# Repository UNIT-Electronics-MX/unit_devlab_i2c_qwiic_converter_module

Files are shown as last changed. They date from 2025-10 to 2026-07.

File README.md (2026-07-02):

# DevLab: I2C Qwiic Converter Module

A bidirectional I2C level shifter module for seamless 3.3V↔5V communication. Features integrated voltage regulators and Qwiic/STEMMA QT connectors for easy sensor integration.

## Key Features

- **Bidirectional Level Shifting:** DIP switch selectable for buck (5V→3.3V) or boost (3.3V→5V)
- **Qwiic/STEMMA QT Compatible:** Daisy-chain multiple sensors effortlessly
- **Compact Design:** Breadboard-friendly with minimal footprint
- **No Additional Wiring:** Integrated power conversion for mixed-voltage systems

<div align="center">
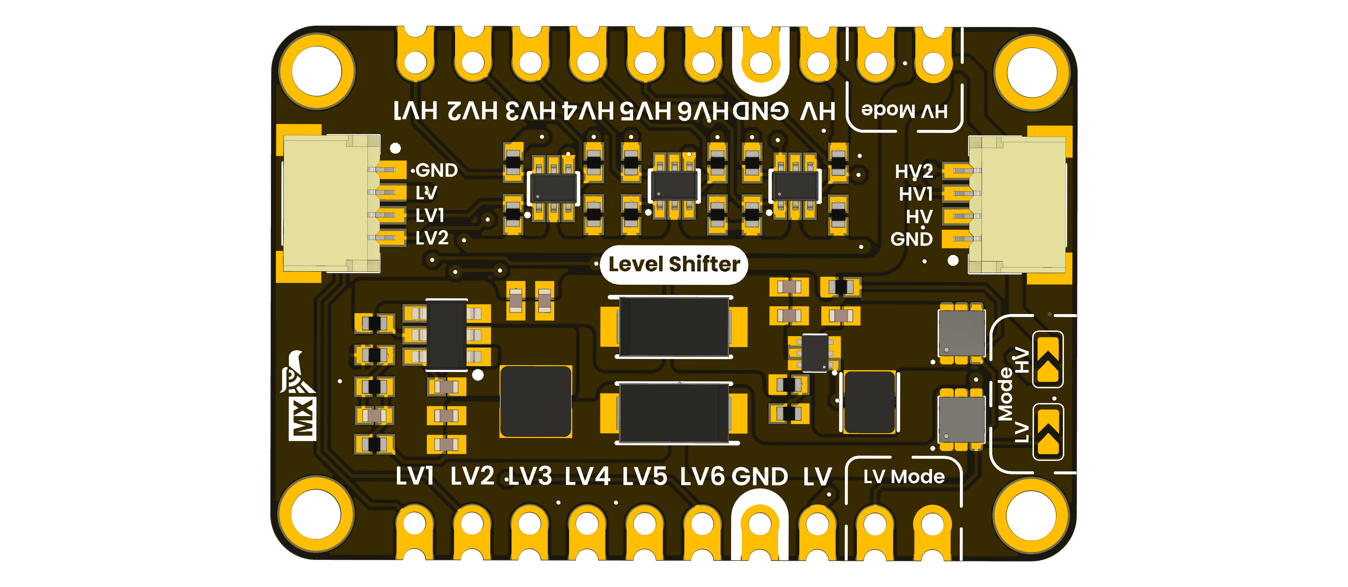
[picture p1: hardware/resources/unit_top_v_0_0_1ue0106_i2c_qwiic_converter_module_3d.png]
  
  <p><em>Development Board</em></p>
</div>

## Quick Start

<div align="center">

[](#)
[](./hardware/unit_datasheet_v_1_0_0_devlab_i2c_Qwiic_converter_module.pdf)
[](#)
[](./software/examples/)

</div >

## Specifications

<div align="center">

| Specification | Value |
|---|---|
| Input Voltage (High) | 5V ± 0.3V |
| Input Voltage (Low) | 3.3V ± 0.1V |
| I2C Speed | 100 kHz - 400 kHz |
| Connector | Qwiic/STEMMA QT |
| Operating Temp | 0°C to 50°C |

</div>

## Use Cases

- Mixed-voltage IoT projects
- Multi-sensor prototyping
- I2C device bridging

## 📝 License

Licensed under the **MIT License**. See [`LICENSE.md`](LICENSE.md).

<div align="center">
  <sub>Created by UNIT Electronics</sub>
</div>

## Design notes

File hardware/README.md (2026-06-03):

# Hardware

<div align="center">
<a href="https://github.com/UNIT-Electronics-MX/unit_devlab_i2c_qwiic_converter_module/blob/main/hardware/unit_sch_v_1_0_0_ue0106_i2c_qwiic_converter_module.pdf">
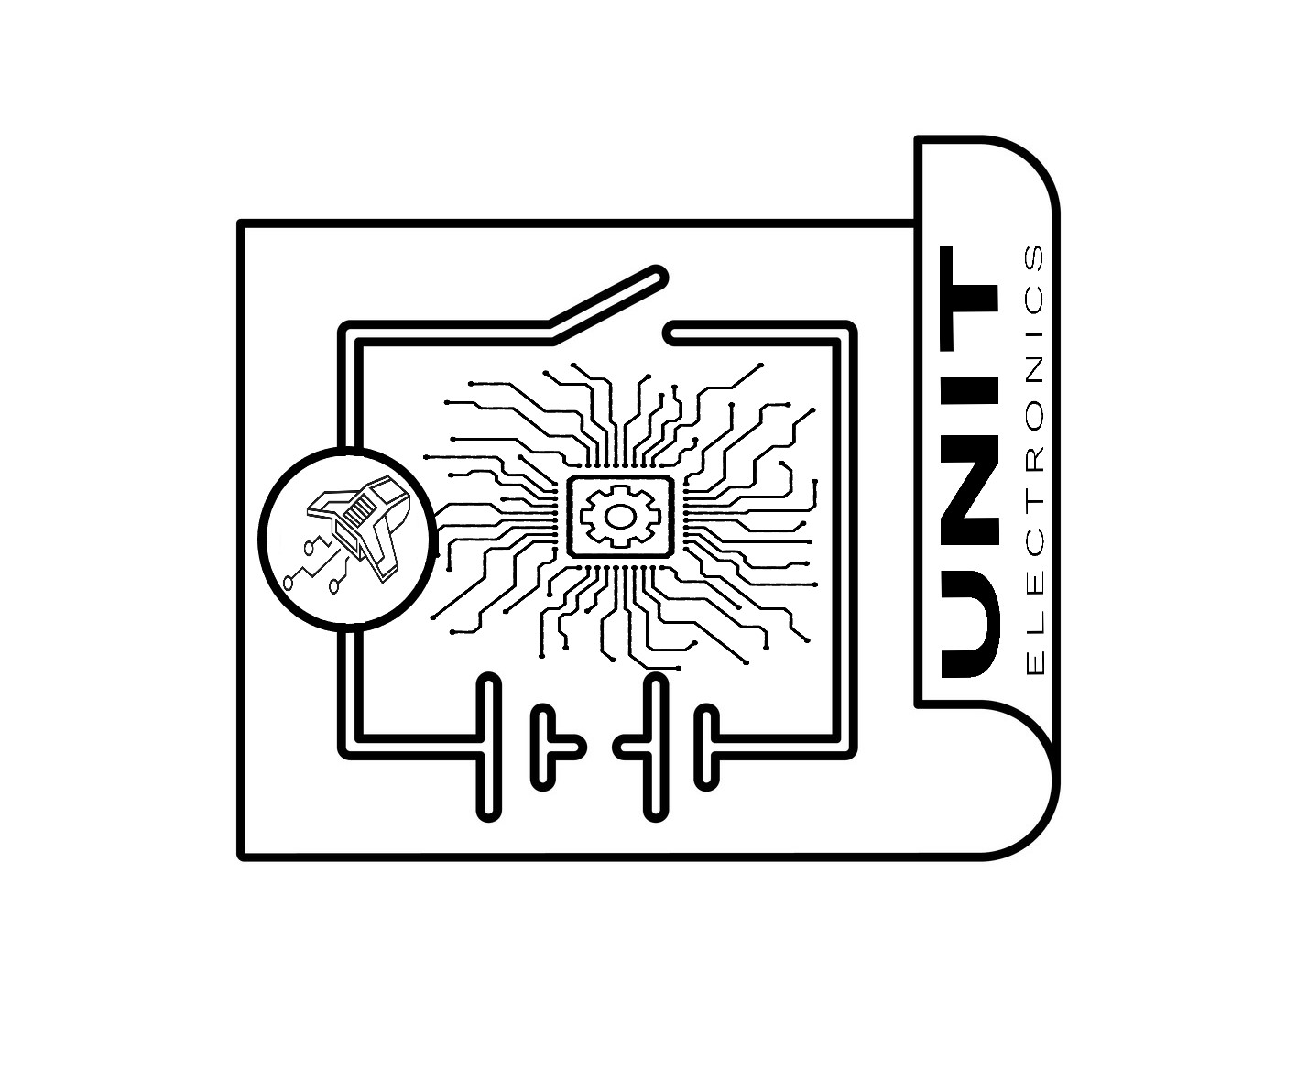
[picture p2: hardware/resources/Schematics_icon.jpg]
<br/>
Schematic
</a>
</div>

---

## Electrical Characteristics

| Parameter | Description | Min | Typ | Max | Unit |
|---|---|---|---|---|---|
| VIN | Input supply voltage for module operation | 2.5 | 3.3 / 5.0 | 5.5 | V |
| VLV | Low-voltage rail operating range | 1.8 | 3.3 | 5.0 | V |
| VHV | High-voltage rail operating range | 3.3 | 5.0 | V |
| IOUT-LV | Maximum output current for LV rail | - | - | 1 | A |
| IOUT-HV | Maximum output current for HV rail | - | - | 1 | A |
| VIH | Input high-level voltage for I²C logic | 0.7 × VCC | - | - | V |
| VIL | Input low-level voltage for I²C logic | - | - | 0.3 × VCC | V |
| VOH | Output high-level voltage for I²C logic | 0.8 × VCC | - | - | V |
| VOL | Output low-level voltage for I²C logic | - | - | 0.2 × VCC | V |
| fI2C | Supported I²C bus frequency | 0 | 100 | 400 | kHz |
| TAMB | Recommended operating ambient temperature | -20 | 25 | 85 | °C |
| RPULLUP | Integrated pull-up resistor value | - | 10 | - | kΩ |
| ESD | ESD protection level (HBM typical) | - | ±2 | - | kV |

> **Note 1:** Maximum output current depends on thermal dissipation, PCB layout, and input voltage conditions.

> **Note 2:** The module integrates bidirectional MOSFET-based level shifters optimized for open-drain I²C communication.

> **Note 3:** Qwiic/STEMMA QT connectors share the same I²C bus signals (VCC, GND, SDA, SCL) for daisy-chain operation.

> **Note 4:** Operating voltage ranges may vary depending on external power configuration and selected LV/HV mode.

## Pinout

<div align="center">
<a href="unit_pinout_v_1_0_0_ue0106_convertidor_qwiic_en.pdf">
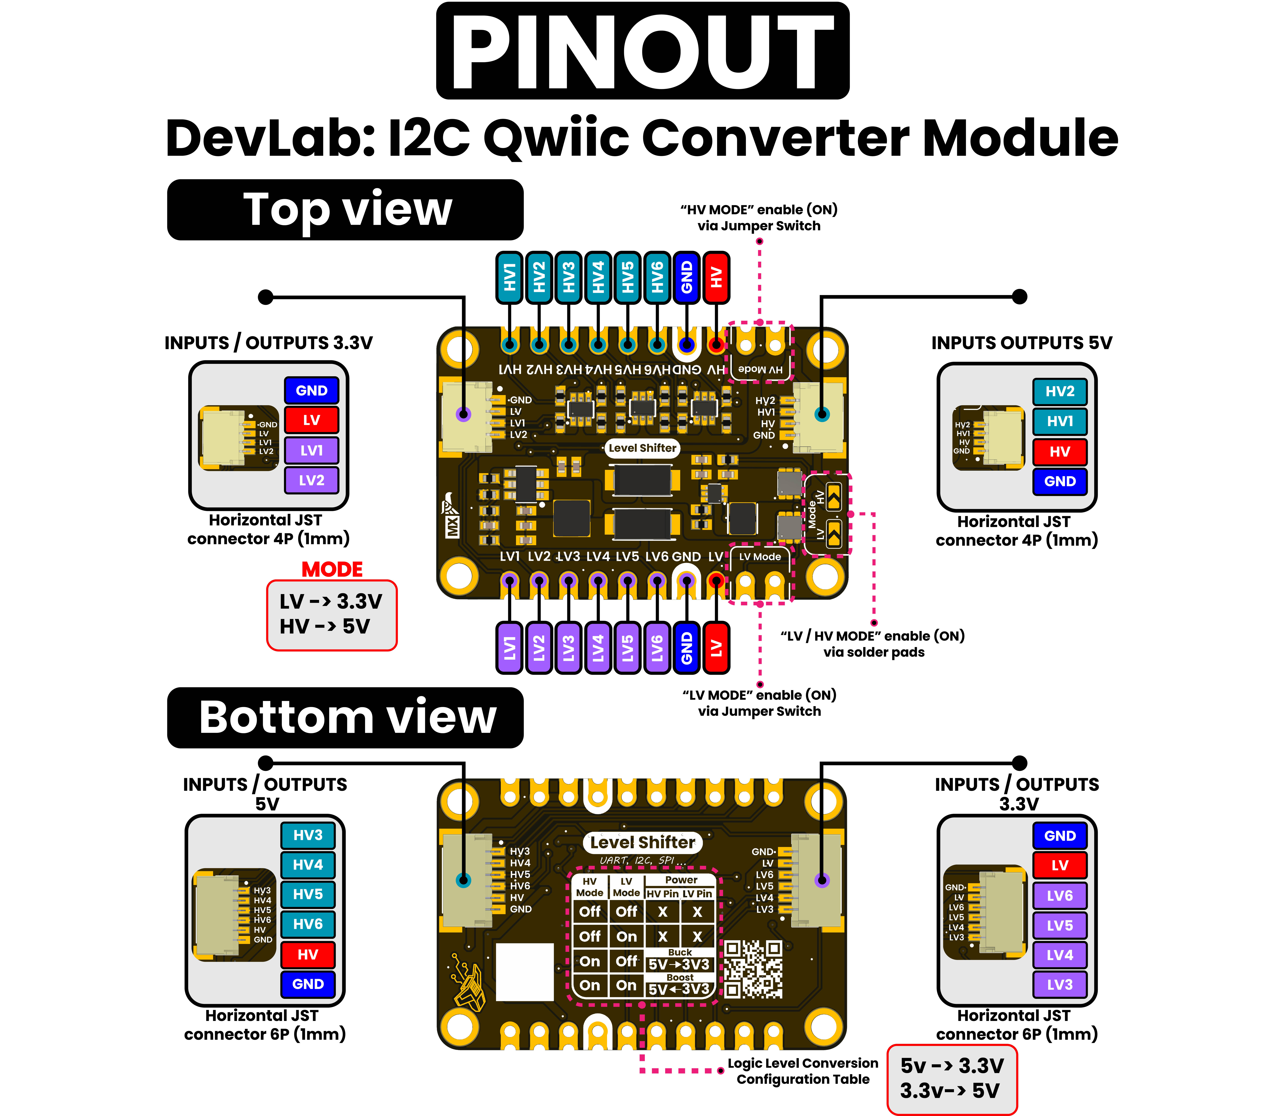
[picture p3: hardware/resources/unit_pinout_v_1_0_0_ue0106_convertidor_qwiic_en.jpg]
<br/>
Pinout
</a>
</div>

### Pin & Connector Layout

| Pin Label | Function | Notes |
|---|---|---|
| VCC | Power Supply | 3.3V or 5V |
| GND | Ground | Common ground for all components |

---

## Dimensions

<div align="center">
<a href="./resources/unit_dimensions_v_1_0_0_ue0106_i2c_qwiic_converter_module.png">
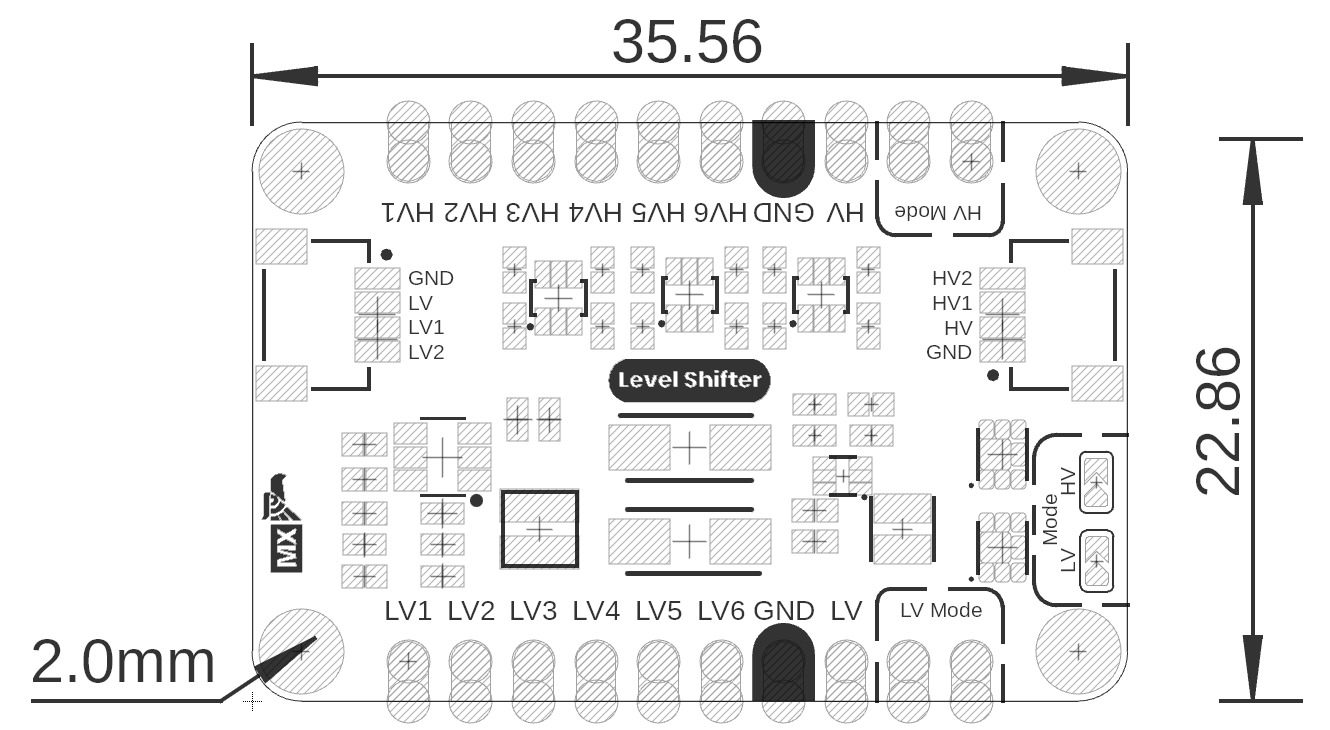
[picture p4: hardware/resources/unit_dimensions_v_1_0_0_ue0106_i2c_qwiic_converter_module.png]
<br/>
Dimensions
</a>
</div>

---

## Topology

<div align="center">
<a href="./resources/unit_topology_v_1_0_0_ue0106_i2c_qwiic_converter_module.png">
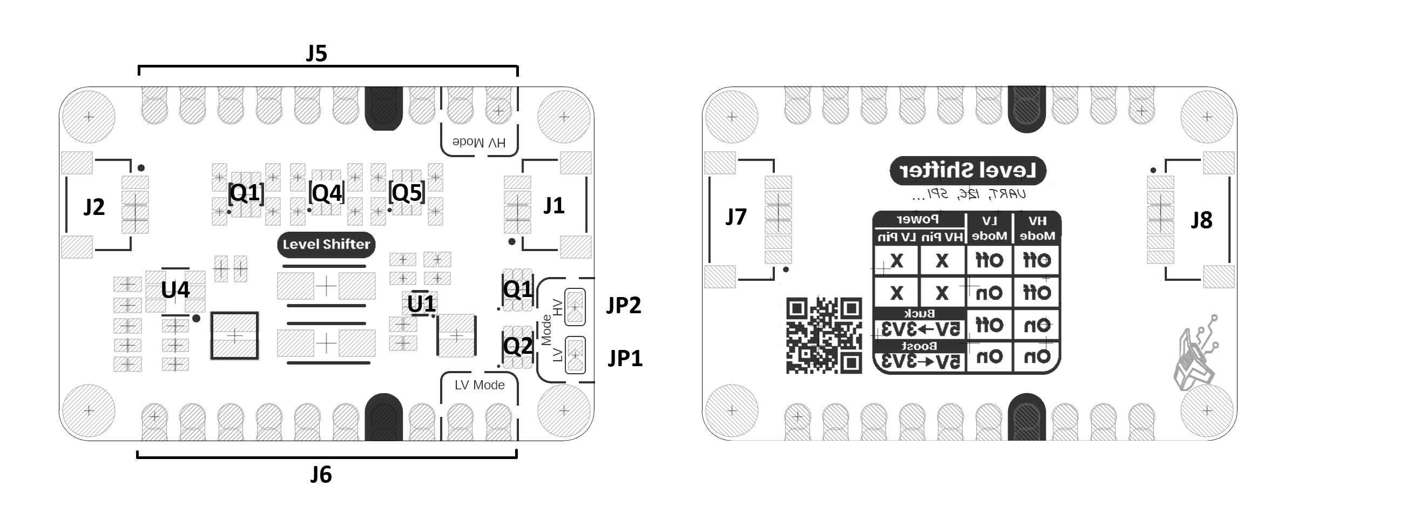
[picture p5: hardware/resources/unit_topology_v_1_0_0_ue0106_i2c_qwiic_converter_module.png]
<br/>
Topology
</a>
</div>

### Topology Description

| Ref. | Description |
|---|---|
| U1 | Boost converter circuit based on TPS61023 for LV power rail generation |
| U4 | Buck converter circuit based on TPS54302DDCT for HV power rail generation |
| Q1, Q4, Q5 | Bidirectional I²C level shifter circuits based on 2N7002KDW MOSFETs |
| Q2, Q3 | Power switching MOSFET stage for voltage rail selection/control |
| J1, J2 | Qwiic/STEMMA QT connectors (JST 1.0 mm pitch) for I²C interface |
| J5, J6 | Castellated 1x10 pin headers (2.54 mm pitch) for external module integration |
| J7, J8 | 1x6 pin headers/connectors for HV/LV mode configuration and external interfacing |
| JP1 | LV Mode solder jumper selector |
| JP2 | HV Mode solder jumper selector |

> **Note:** The module also includes a Qwiic/STEMMA QT connector carrying the same four signals (VCC, GND, SDA, SCL) for effortless daisy-chaining.

---

## Functional Description

The **DevLab Qwiic I²C Converter Module** is a bidirectional voltage level shifter designed for seamless communication between low-voltage and high-voltage I²C devices. The module enables safe interfacing between 3.3V and 5V systems using MOSFET-based bidirectional level translation.

The design integrates dedicated boost and buck power conversion stages to generate and regulate the required voltage rails for both LV and HV domains. Multiple Qwiic/STEMMA QT connectors and castellated interfaces simplify integration with embedded systems, development boards, sensors, and expansion modules.

### Features

- Bidirectional I²C level shifting
- Qwiic/STEMMA QT compatibility
- Castellated edge connections for embedded integration
- Configurable LV/HV operating modes
- 3.3V and 5V logic interoperability
- Daisy-chain I²C connectivity

### Typical Applications

- Sensor interfacing
- Mixed-voltage embedded systems
- Rapid prototyping
- Development board expansion
- Qwiic/STEMMA QT ecosystem integration

# References

- [TPS61023 Datasheet](https://www.ti.com/lit/ds/symlink/tps61023.pdf)
- [TPS54302 Datasheet](https://www.ti.com/lit/ds/symlink/tps54302.pdf)
- [2N7002KDW Datasheet](https://assets.nexperia.com/documents/data-sheet/2N7002KDW.pdf)

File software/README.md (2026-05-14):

## Buck Mode

### 5 V to 3.3 V Level Conversion

To enable **Buck Mode**, the module must be configured to convert a high-voltage signal into a lower-voltage signal. In this case, the input signal comes from a **5 V microcontroller**, and the module shifts it down to a **3.3 V logic level**.

There are two ways to enable this mode:

1. Place a jumper on the **HV Mode** pins.
2. Solder the exposed pads labeled **HV Mode** for a permanent configuration.

In **Buck Mode**, the input signal must be connected to one of the **HV channels**, from **HV1 to HV6**. The corresponding converted output signal will be available on the matching **LV channel**, from **LV1 to LV6**.

For example:

<div align="center">

| Input Signal | Converted Output |
|---|---|
| `HV1` | `LV1` |
| `HV2` | `LV2` |
| `HV3` | `LV3` |
| `HV4` | `LV4` |
| `HV5` | `LV5` |
| `HV6` | `LV6` |

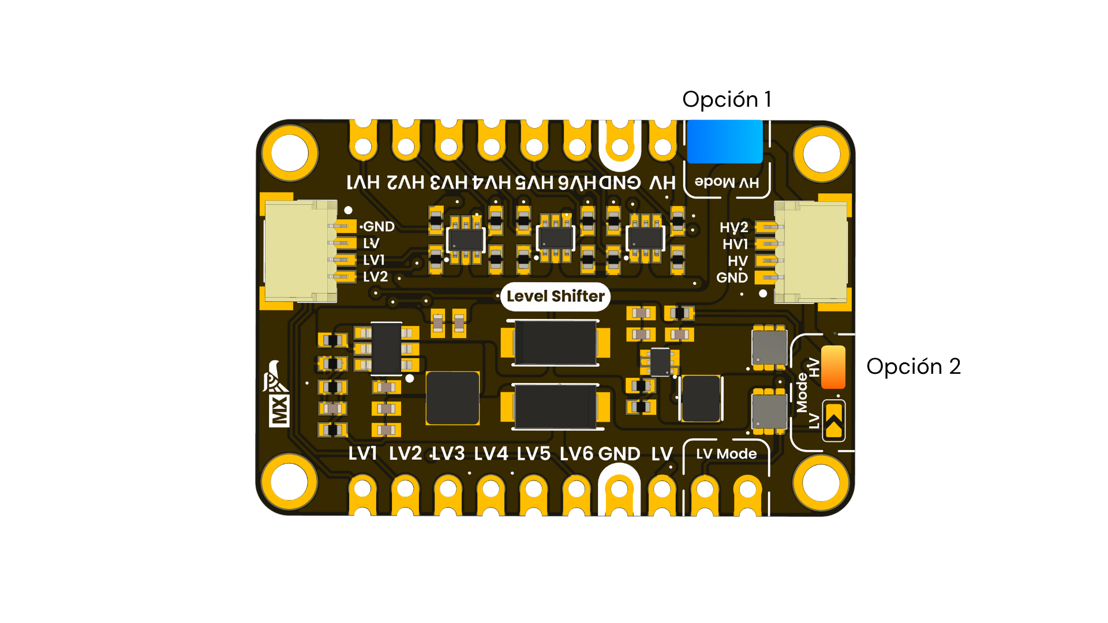
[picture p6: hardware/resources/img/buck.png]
Buck mode jumper configuration
  
  <p><em>Buck Mode jumper configuration</em></p>
</div>

---

## Example Circuit

The following image shows a basic test circuit using an **Arduino UNO** and the **I2C QWIIC Converter Module**.

In this setup, the Arduino UNO generates a square wave. Since the Arduino UNO operates with **5 V logic**, the generated signal enters the converter module through one of the **HV channels**. In this example, the signal is connected to **HV4**, which corresponds to **High Voltage Channel 1**.

The **5 V** supply from the Arduino is connected to the **HV** pin of the module, defining the high-voltage side as **5 V**. After placing the required jumper on the **HV Mode** pins, the module converts the square wave from **5 V** to **3.3 V**. The converted signal can then be measured or used from the corresponding low-voltage output, **LV4**.

To verify the conversion, an oscilloscope is used:

- **Oscilloscope Channel 1:** connected to **HV4**, where the original **5 V signal** from the microcontroller is observed.
- **Oscilloscope Channel 2:** connected to **LV4**, where the converted **3.3 V signal** is observed.

This test makes it possible to compare both signals and confirm that the module is correctly shifting the logic level from **5 V to 3.3 V**.

<div align="center">
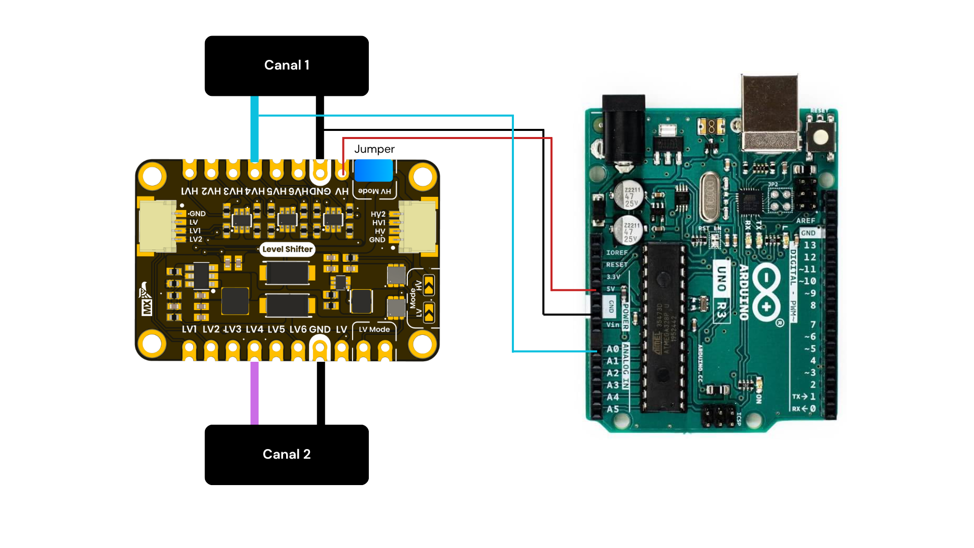
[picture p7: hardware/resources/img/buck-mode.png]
Buck mode test circuit
  
  <p><em>Buck Mode test circuit</em></p>
</div>

## Boost Mode

### 3.3 V to 5 V Level Conversion

To enable **Boost Mode**, the module must be configured to convert a low-voltage signal into a higher-voltage signal. In this case, the input signal comes from a **3.3 V microcontroller**, and the module shifts it to a **5 V logic level**.

There are two ways to enable this mode:

1. Place one jumper on the **HV Mode** pins and another jumper on the **LV Mode** pins.
2. Solder the exposed pads labeled **HV Mode** and **LV Mode** for a permanent configuration.

<div align="center">
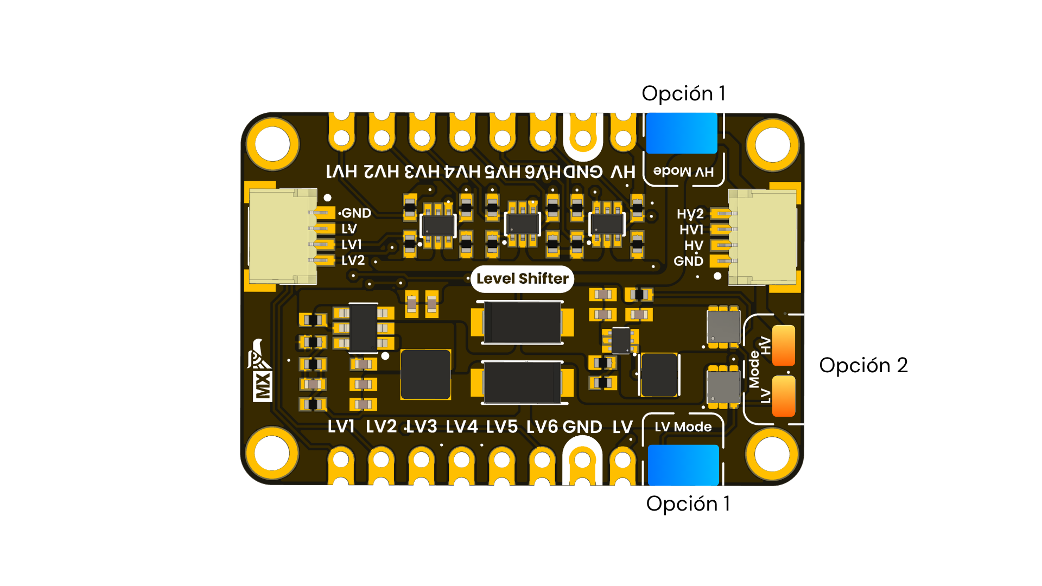
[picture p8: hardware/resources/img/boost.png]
Boost mode jumper configuration
  
  <p><em>Boost Mode jumper configuration</em></p>
</div>

---

## Example Circuit

The following image shows a basic test circuit using the **UNIT Pulsar C6** development board and the **I2C QWIIC Converter Module**.

In this setup, a **JST QWIIC cable** is connected from the development board to the level converter module. The square wave generated by the microcontroller on **GPIO6** is connected to **LV1**, which corresponds to **Low Voltage Channel 1**. The microcontroller supply voltage is also connected to the **LV** pin, defining the low-voltage side as **3.3 V**.

After placing the required jumpers on the **HV Mode** and **LV Mode** terminals, the module converts the square wave from **3.3 V** to **5 V**. This allows the signal generated by the microcontroller to be used with circuits or devices that require **5 V logic levels**.

To verify the conversion, an oscilloscope is used:

- **Oscilloscope Channel 1:** connected to **HV1**, where the converted **5 V signal** is observed.
- **Oscilloscope Channel 2:** connected to **LV1**, where the original **3.3 V signal** from the microcontroller is observed.

This test makes it possible to compare both signals and confirm that the module is correctly shifting the logic level from **3.3 V to 5 V**.

<div align="center">
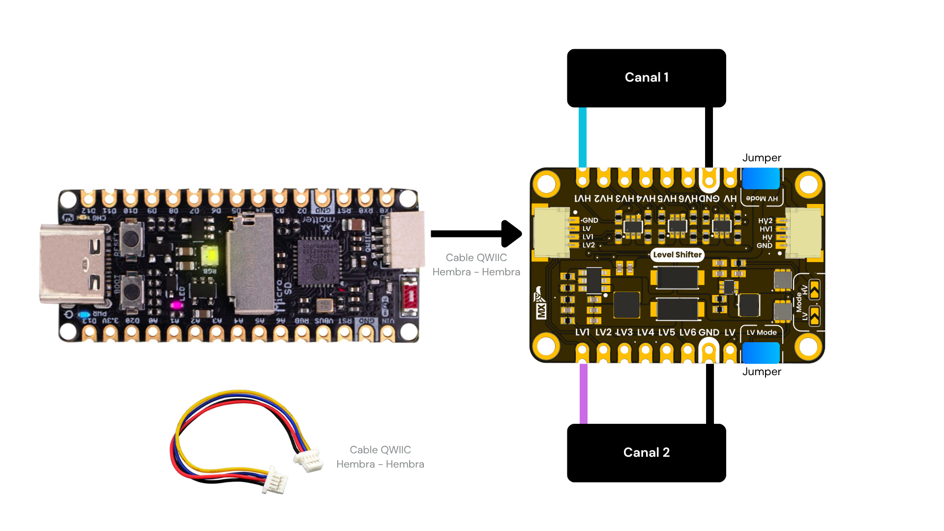
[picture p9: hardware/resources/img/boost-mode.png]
Boost mode test circuit
  
  <p><em>Boost Mode test circuit</em></p>
</div>

---

## Oscilloscope Verification

The oscilloscope capture shows the behavior of the signal before and after passing through the level converter module.

In this test, the original square wave is generated by the **UNIT Pulsar C6** microcontroller at **3.3 V logic level** and is applied to the low-voltage side of the module. After the signal passes through the converter in **Boost Mode**, the output signal is shifted to approximately **5 V logic level**.

The two oscilloscope channels allow both signals to be compared at the same time:

- **Channel 1:** original signal on the **LV side**, approximately **3.3 V**.
- **Channel 2:** converted signal on the **HV side**, approximately **5 V**.

Both waveforms keep the same timing behavior, including the pulse width, period, and duty cycle. The main difference between them is the voltage amplitude. This confirms that the module is correctly converting the logic level from **3.3 V to 5 V** without modifying the shape of the digital signal.

<div align="center">
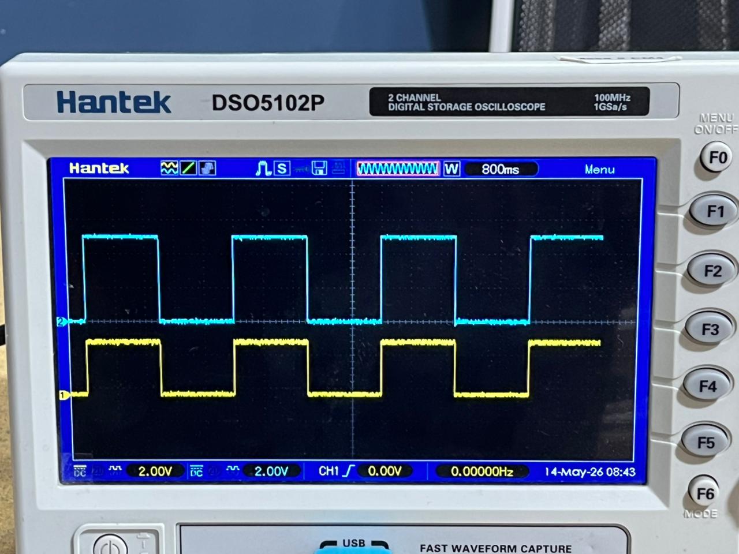
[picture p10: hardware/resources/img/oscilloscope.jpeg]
Boost mode oscilloscope verification
  
  <p><em>Boost Mode oscilloscope verification</em></p>
</div>

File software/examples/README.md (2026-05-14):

# Software Examples

In this example, the microcontroller generates a slow square wave on **GPIO6**. Since the microcontroller operates at **3.3 V logic**, the output signal is originally a **3.3 V digital pulse train**.

The signal is then connected to the **I2C QWIIC Converter Module**, which works as a logic level converter. In this configuration, the module converts the input signal from **3.3 V to 5 V**, allowing the square wave generated by the microcontroller to be observed or used as a **5 V logic signal** at the module output.

This test is useful to verify the module’s level-shifting behavior and to confirm that a low-voltage digital signal from a 3.3 V microcontroller can be safely adapted for circuits or devices that require 5 V logic levels.

---

## Arduino C++ Version

```cpp
const int pulsePin = 6;      // GPIO6
const int highTime = 2000;   // HIGH time: 2000 ms = 2 seconds
const int lowTime = 2000;    // LOW time: 2000 ms = 2 seconds

void setup() {
  pinMode(pulsePin, OUTPUT); // Configure GPIO6 as an output
}

void loop() {
  digitalWrite(pulsePin, HIGH); // Set GPIO6 HIGH
  delay(highTime);              // Wait 2 seconds

  digitalWrite(pulsePin, LOW);  // Set GPIO6 LOW
  delay(lowTime);               // Wait 2 seconds
}
```

---

## Arduino C++ Explanation

This program generates a slow digital pulse signal on **GPIO6**.

```cpp
const int pulsePin = 6;
```

This line defines the output pin. In this case, the pulse train will be generated on **GPIO6**.

```cpp
const int highTime = 2000;
const int lowTime = 2000;
```

These constants define how long the signal stays in each state. In Arduino, the `delay()` function uses milliseconds, so `2000 ms` is equal to `2 seconds`.

```cpp
pinMode(pulsePin, OUTPUT);
```

This line configures GPIO6 as a digital output pin.

```cpp
digitalWrite(pulsePin, HIGH);
```

This sets GPIO6 to a HIGH logic level. Depending on the board, this is usually **3.3 V** or **5 V**.

```cpp
delay(highTime);
```

This keeps the pin HIGH for 2 seconds.

```cpp
digitalWrite(pulsePin, LOW);
```

This sets GPIO6 to a LOW logic level, usually **0 V**.

```cpp
delay(lowTime);
```

This keeps the pin LOW for 2 seconds.

Since the code is inside `loop()`, the sequence repeats forever.

---

## MicroPython Version

```python
from machine import Pin
from time import sleep

pulse_pin = Pin(6, Pin.OUT)  # Configure GPIO6 as an output

high_time = 2  # HIGH time: 2 seconds
low_time = 2   # LOW time: 2 seconds

while True:
    pulse_pin.value(1)  # Set GPIO6 HIGH
    sleep(high_time)    # Wait 2 seconds

    pulse_pin.value(0)  # Set GPIO6 LOW
    sleep(low_time)     # Wait 2 seconds
```

---

## MicroPython Explanation

This MicroPython program performs the same task as the Arduino C++ version: it generates a slow pulse train on **GPIO6**.

```python
from machine import Pin
from time import sleep
```

The `Pin` class is used to configure and control GPIO pins. The `sleep()` function is used to pause the program for a specific number of seconds.

```python
pulse_pin = Pin(6, Pin.OUT)
```

This line configures **GPIO6** as a digital output.

```python
high_time = 2
low_time = 2
```

These variables define how long the signal stays HIGH and LOW. In MicroPython, `sleep()` uses seconds, so the value `2` means 2 seconds.

```python
while True:
```

This creates an infinite loop. The pulse train will continue running as long as the board is powered.

```python
pulse_pin.value(1)
```

This sets GPIO6 to a HIGH logic level.

```python
sleep(high_time)
```

This keeps the signal HIGH for 2 seconds.

```python
pulse_pin.value(0)
```

This sets GPIO6 to a LOW logic level.

```python
sleep(low_time)
```

This keeps the signal LOW for 2 seconds.

---

## Signal Behavior

Both programs generate the following signal:

```text
HIGH for 2 seconds
LOW for 2 seconds
HIGH for 2 seconds
LOW for 2 seconds
...
```

The total period of the signal is:

```text
Period = HIGH time + LOW time
Period = 2 s + 2 s
Period = 4 s
```

The frequency is:

```text
Frequency = 1 / Period
Frequency = 1 / 4 s
Frequency = 0.25 Hz
```

The duty cycle is:

```text
Duty Cycle = HIGH time / Period × 100
Duty Cycle = 2 s / 4 s × 100
Duty Cycle = 50%
```

---

## Summary

| Parameter | Value |
|---|---:|
| GPIO pin | GPIO6 |
| HIGH time | 2 seconds |
| LOW time | 2 seconds |
| Period | 4 seconds |
| Frequency | 0.25 Hz |
| Duty cycle | 50% |

The Arduino version uses `digitalWrite()` and `delay()`, while the MicroPython version uses `Pin.value()` and `sleep()`.

Both versions are useful for testing GPIO outputs, LEDs, logic level converters, oscilloscopes, or digital input circuits.

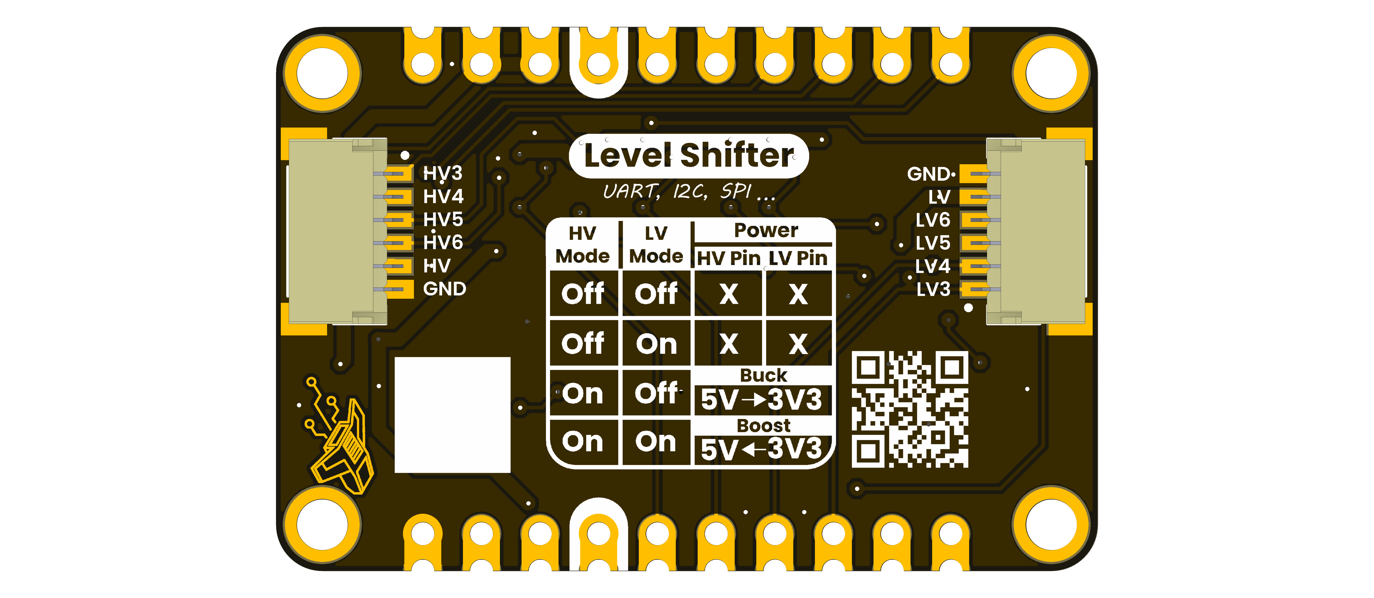
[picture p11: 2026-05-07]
docs/hardware/resources/unit_btm_v_0_0_1ue0106_i2c_qwiic_converter_module_3d.png

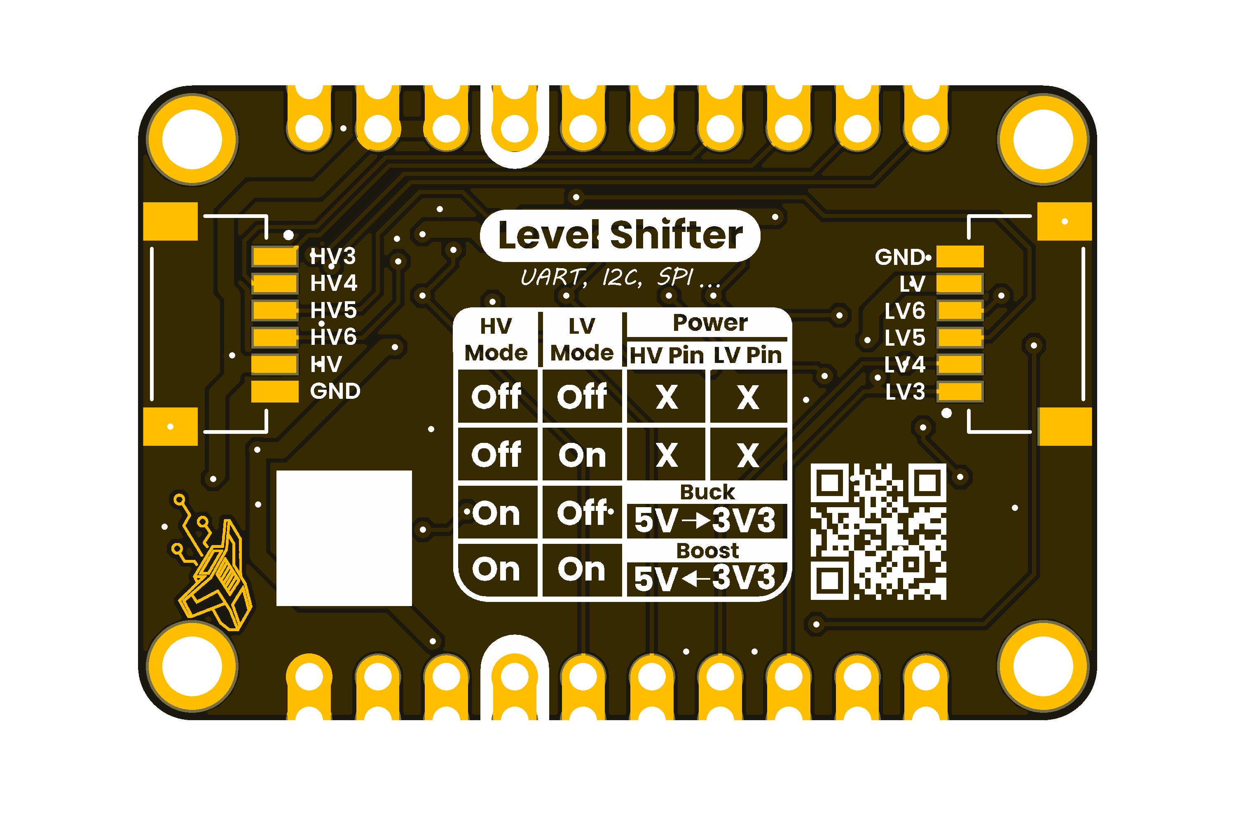
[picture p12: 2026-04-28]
docs/hardware/resources/v1/unit_btm_v_0_0_1_ue0116_i2c_qwiic_converter_module.jpg

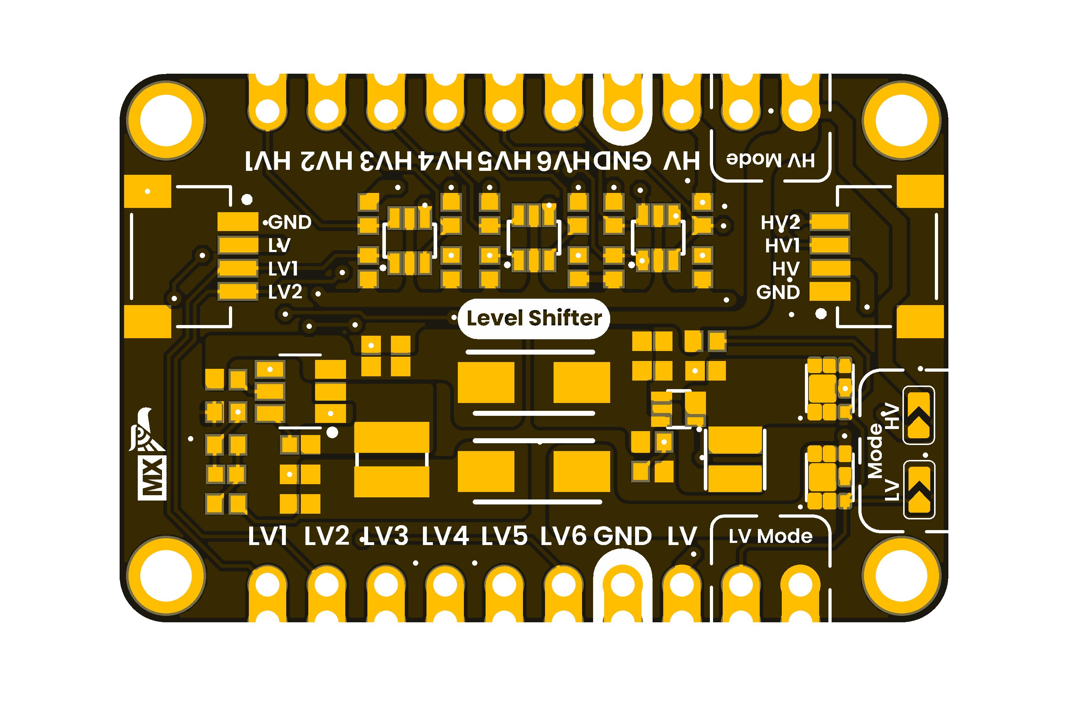
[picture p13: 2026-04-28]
docs/hardware/resources/v1/unit_top_v_0_0_1_ue0116_i2c_qwiic_converter_module.jpg

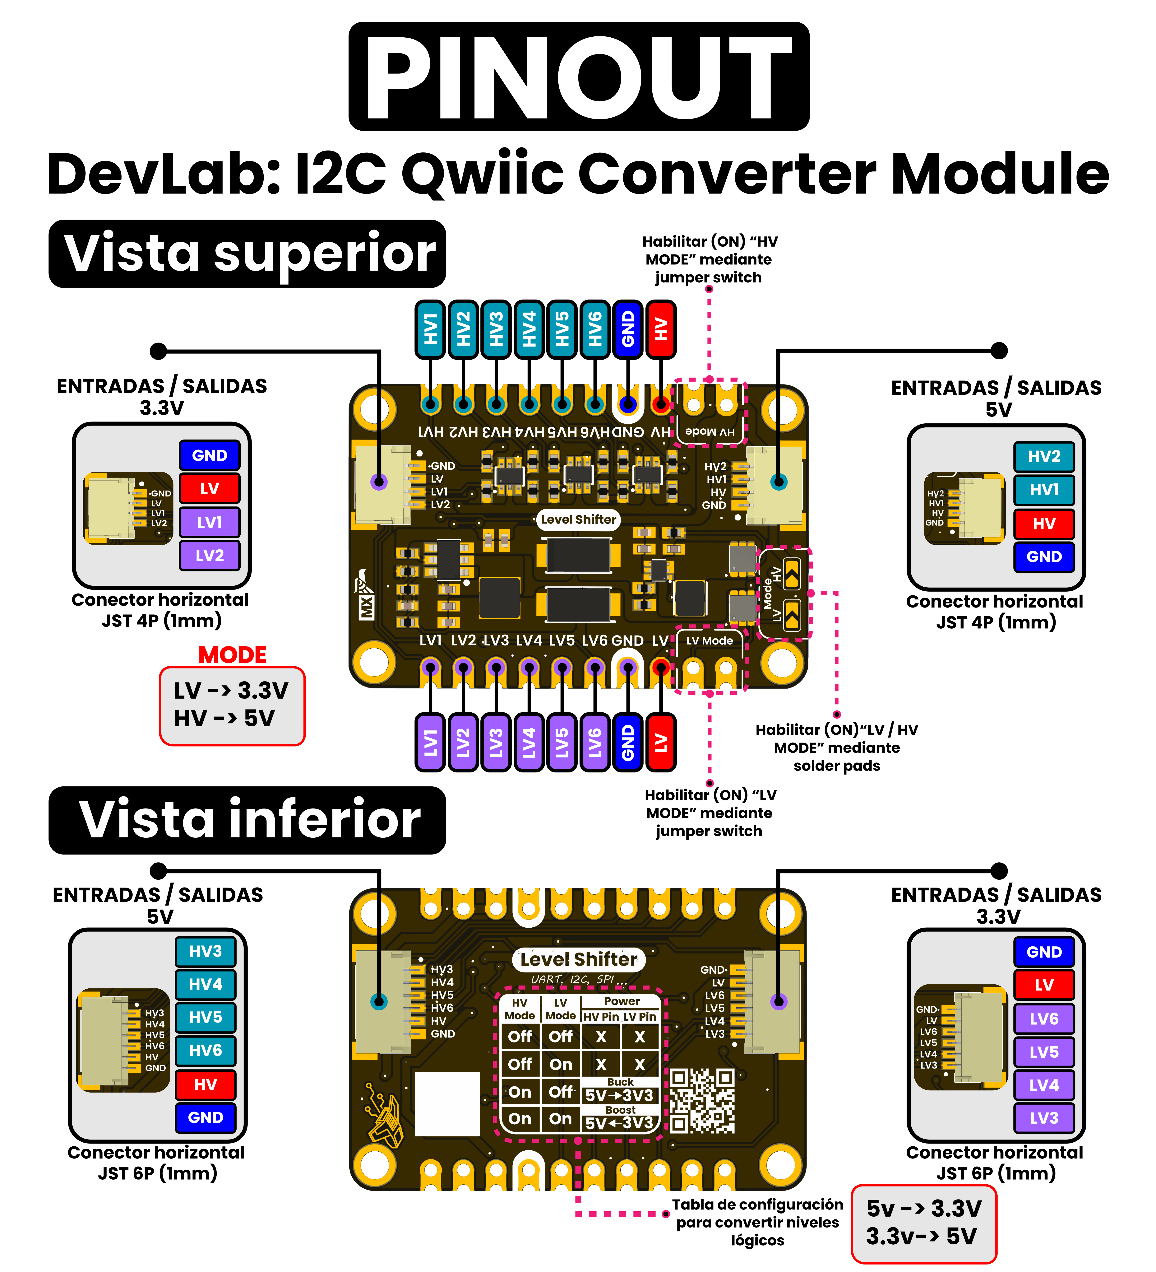
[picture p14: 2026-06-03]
docs/hardware/resources/unit_pinout_v_1_0_0_ue0106_convertidor_qwiic_es_2026-06-03.png

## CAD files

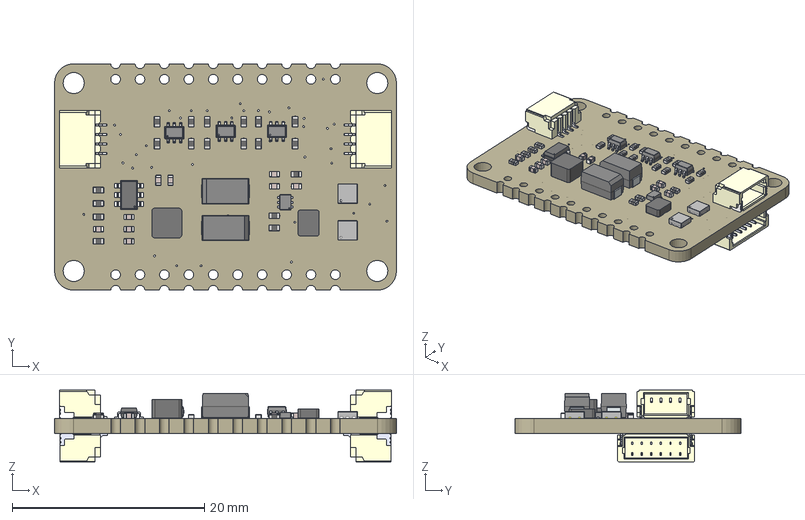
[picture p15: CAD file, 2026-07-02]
docs/hardware/mechanics/unit_3d_v1_0_0_ue0106_I2C_qwiic_converter_module.step
35.6 x 23.5 x 7.48 mm
Placa
M2-THICK-OUTLINE x 4
SM04B-SRSS-TB(LF)(SN)--3DModel-STEP-56544 v1 x 2
SM06B-SRSS-TB(LF)(SN)--3DModel-STEP-269445 v1 x 2
29pS-Q1-PDFN-6_L2.0-W2.0-P0.65-BL-EP x 2
FilletPin1 x 2
FilletPin2 x 2
SOT-563 v1
0402_R x 19

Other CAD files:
docs/hardware/mechanics/unit_3d_v1_0_0_ue0106_I2C_qwiic_converter_module.f3d

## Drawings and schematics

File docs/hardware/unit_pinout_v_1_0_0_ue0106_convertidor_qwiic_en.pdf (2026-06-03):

# PINOUT

# DevLab: I2C Qwiic Converter Module

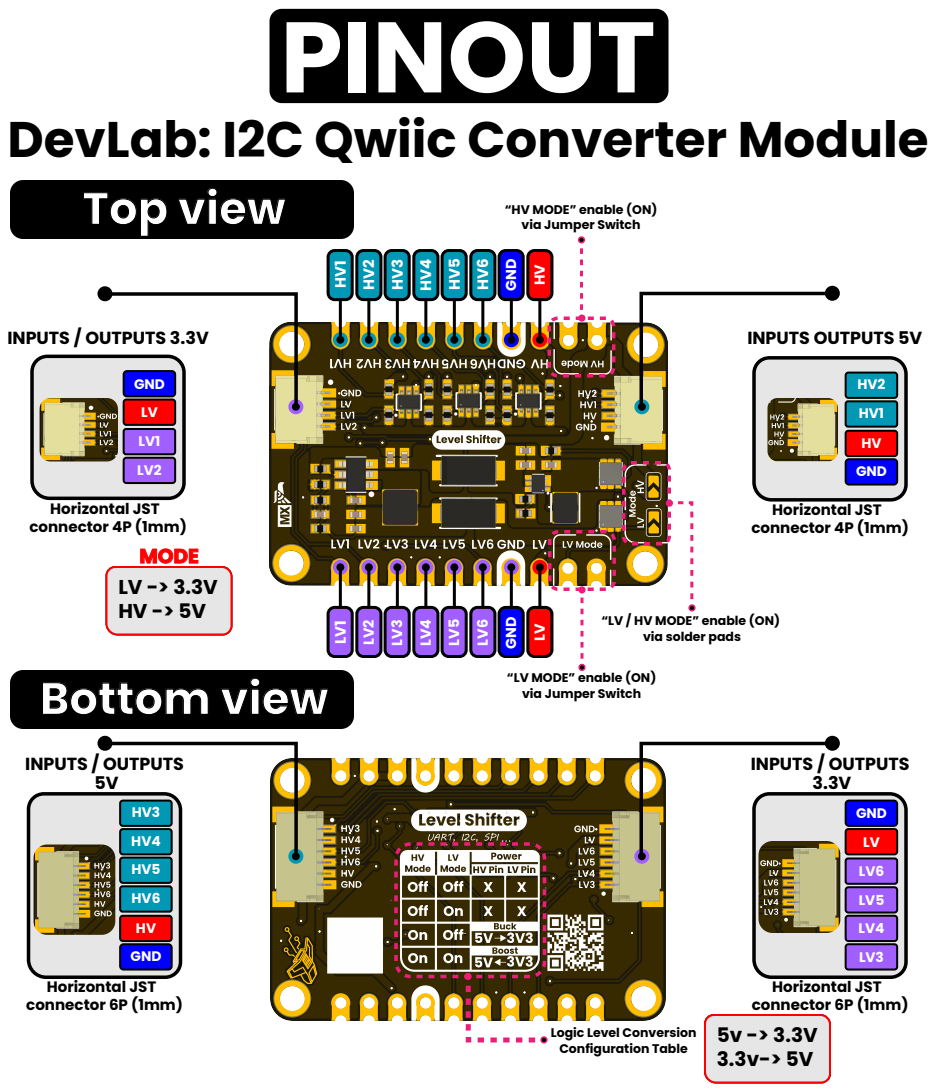
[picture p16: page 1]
Top view; Bottom view; Horizontal JST connector 4P (1mm); GND; MODE; INPUTS / OUTPUTS 3.3V; INPUTS OUTPUTS 5V; Horizontal JST connector 6P (1mm); INPUTS / OUTPUTS 5V

“HV MODE” enable (ON)
via Jumper Switch

“LV / HV MODE” enable (ON)
via solder pads

“LV MODE” enable (ON)

Logic Level Conversion
Configuration Table

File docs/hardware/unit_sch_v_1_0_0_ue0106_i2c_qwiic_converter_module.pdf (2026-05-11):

5V 5V

A

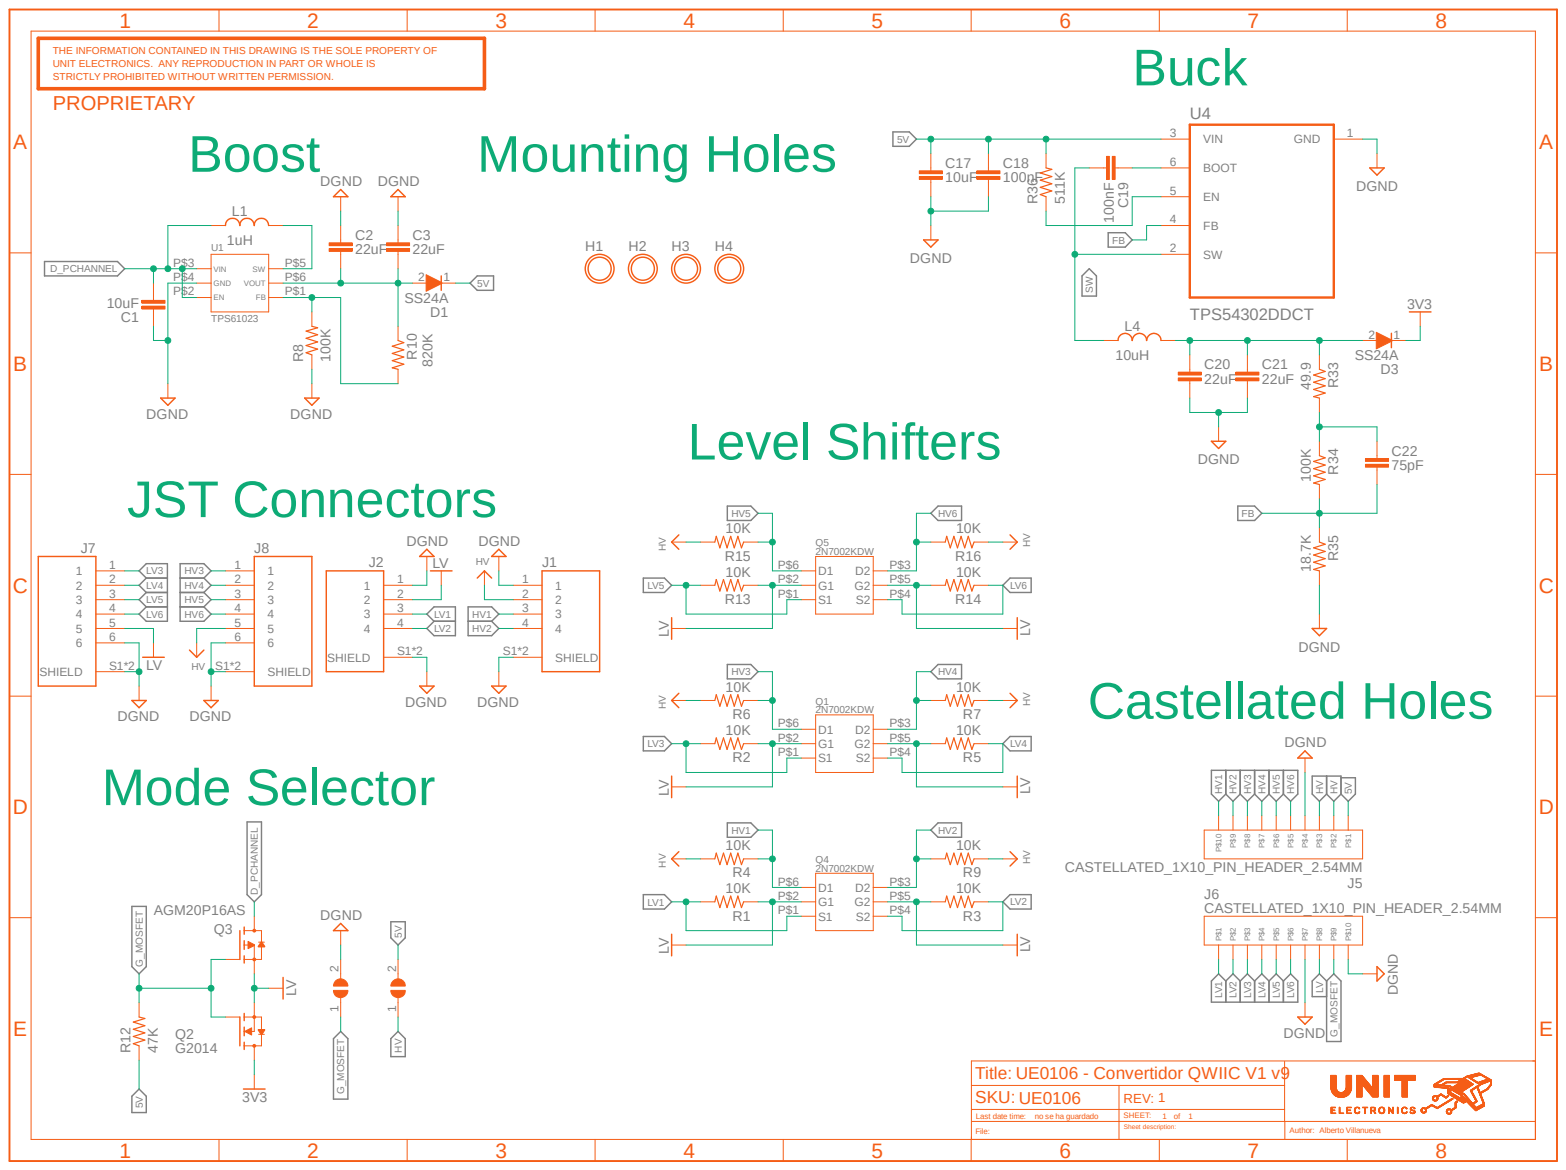
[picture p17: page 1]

THE INFORMATION CONTAINED IN THIS DRAWING IS THE SOLE PROPERTY OF UNIT ELECTRONICS. ANY REPRODUCTION IN PART OR WHOLE IS

STRICTLY PROHIBITED WITHOUT WRITTEN PERMISSION. PROPRIETARY

75pF ⁴⁹.9 100K 18.7K ⁵¹¹K
C22 R³³ R³⁴ R³⁵ R³⁶

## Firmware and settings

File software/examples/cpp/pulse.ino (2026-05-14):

const int pulsePin = 6;      // GPIO6
const int tiempoAlto = 2000; // Tiempo en alto: 1000 ms = 1 segundo
const int tiempoBajo = 2000; // Tiempo en bajo: 1000 ms = 1 segundo

void setup() {
  pinMode(pulsePin, OUTPUT);
}

void loop() {
  digitalWrite(pulsePin, HIGH); // Pulso en alto
  delay(tiempoAlto);

  digitalWrite(pulsePin, LOW);  // Pulso en bajo
  delay(tiempoBajo);
}

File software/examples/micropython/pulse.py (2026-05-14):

from machine import Pin
from time import sleep

pulse_pin = Pin(6, Pin.OUT)  # GPIO6

tiempo_alto = 2  # Tiempo en alto: 2 segundos
tiempo_bajo = 2  # Tiempo en bajo: 2 segundos

while True:
    pulse_pin.value(1)  # Pulso en alto
    sleep(tiempo_alto)

    pulse_pin.value(0)  # Pulso en bajo
    sleep(tiempo_bajo)

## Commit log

2026-05-11 docs: upload schematics ant topology
2026-07-02 docs(mechanics): add 3d models to hardware folder
    [unit_3d_v1_0_0_ue0106_I2C_qwiic_converter_module.f3d, unit_3d_v1_0_0_ue0106_I2C_qwiic_converter_module.step]
2026-07-02 Auto-update hardware documentation [skip ci]
    [unit_3d_v1_0_0_ue0106_I2C_qwiic_converter_module.f3d, unit_3d_v1_0_0_ue0106_I2C_qwiic_converter_module.step]
